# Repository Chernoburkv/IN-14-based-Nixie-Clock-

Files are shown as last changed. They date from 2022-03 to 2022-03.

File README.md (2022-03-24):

# IN-14-based-Nixie-Clock-
Nixie clock with date and calendar on 6 soviet nixie tubes with static indication and voltage doubler for nixies. 
Based on ds3231 and ATmega 8. Powers from 36-42VAC (for example a small transformer).
ECAD files for main & display board, Code::Blocks project, hex and fuse pic included.

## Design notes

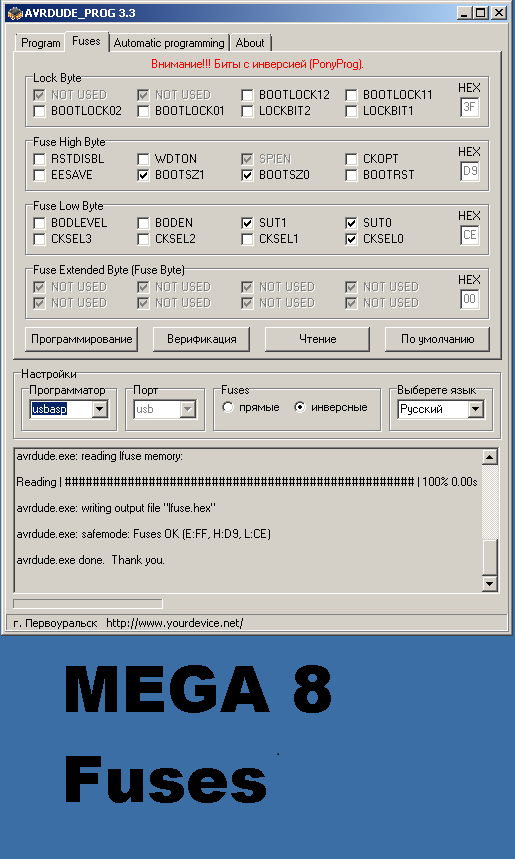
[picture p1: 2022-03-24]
mega8 fuses.png

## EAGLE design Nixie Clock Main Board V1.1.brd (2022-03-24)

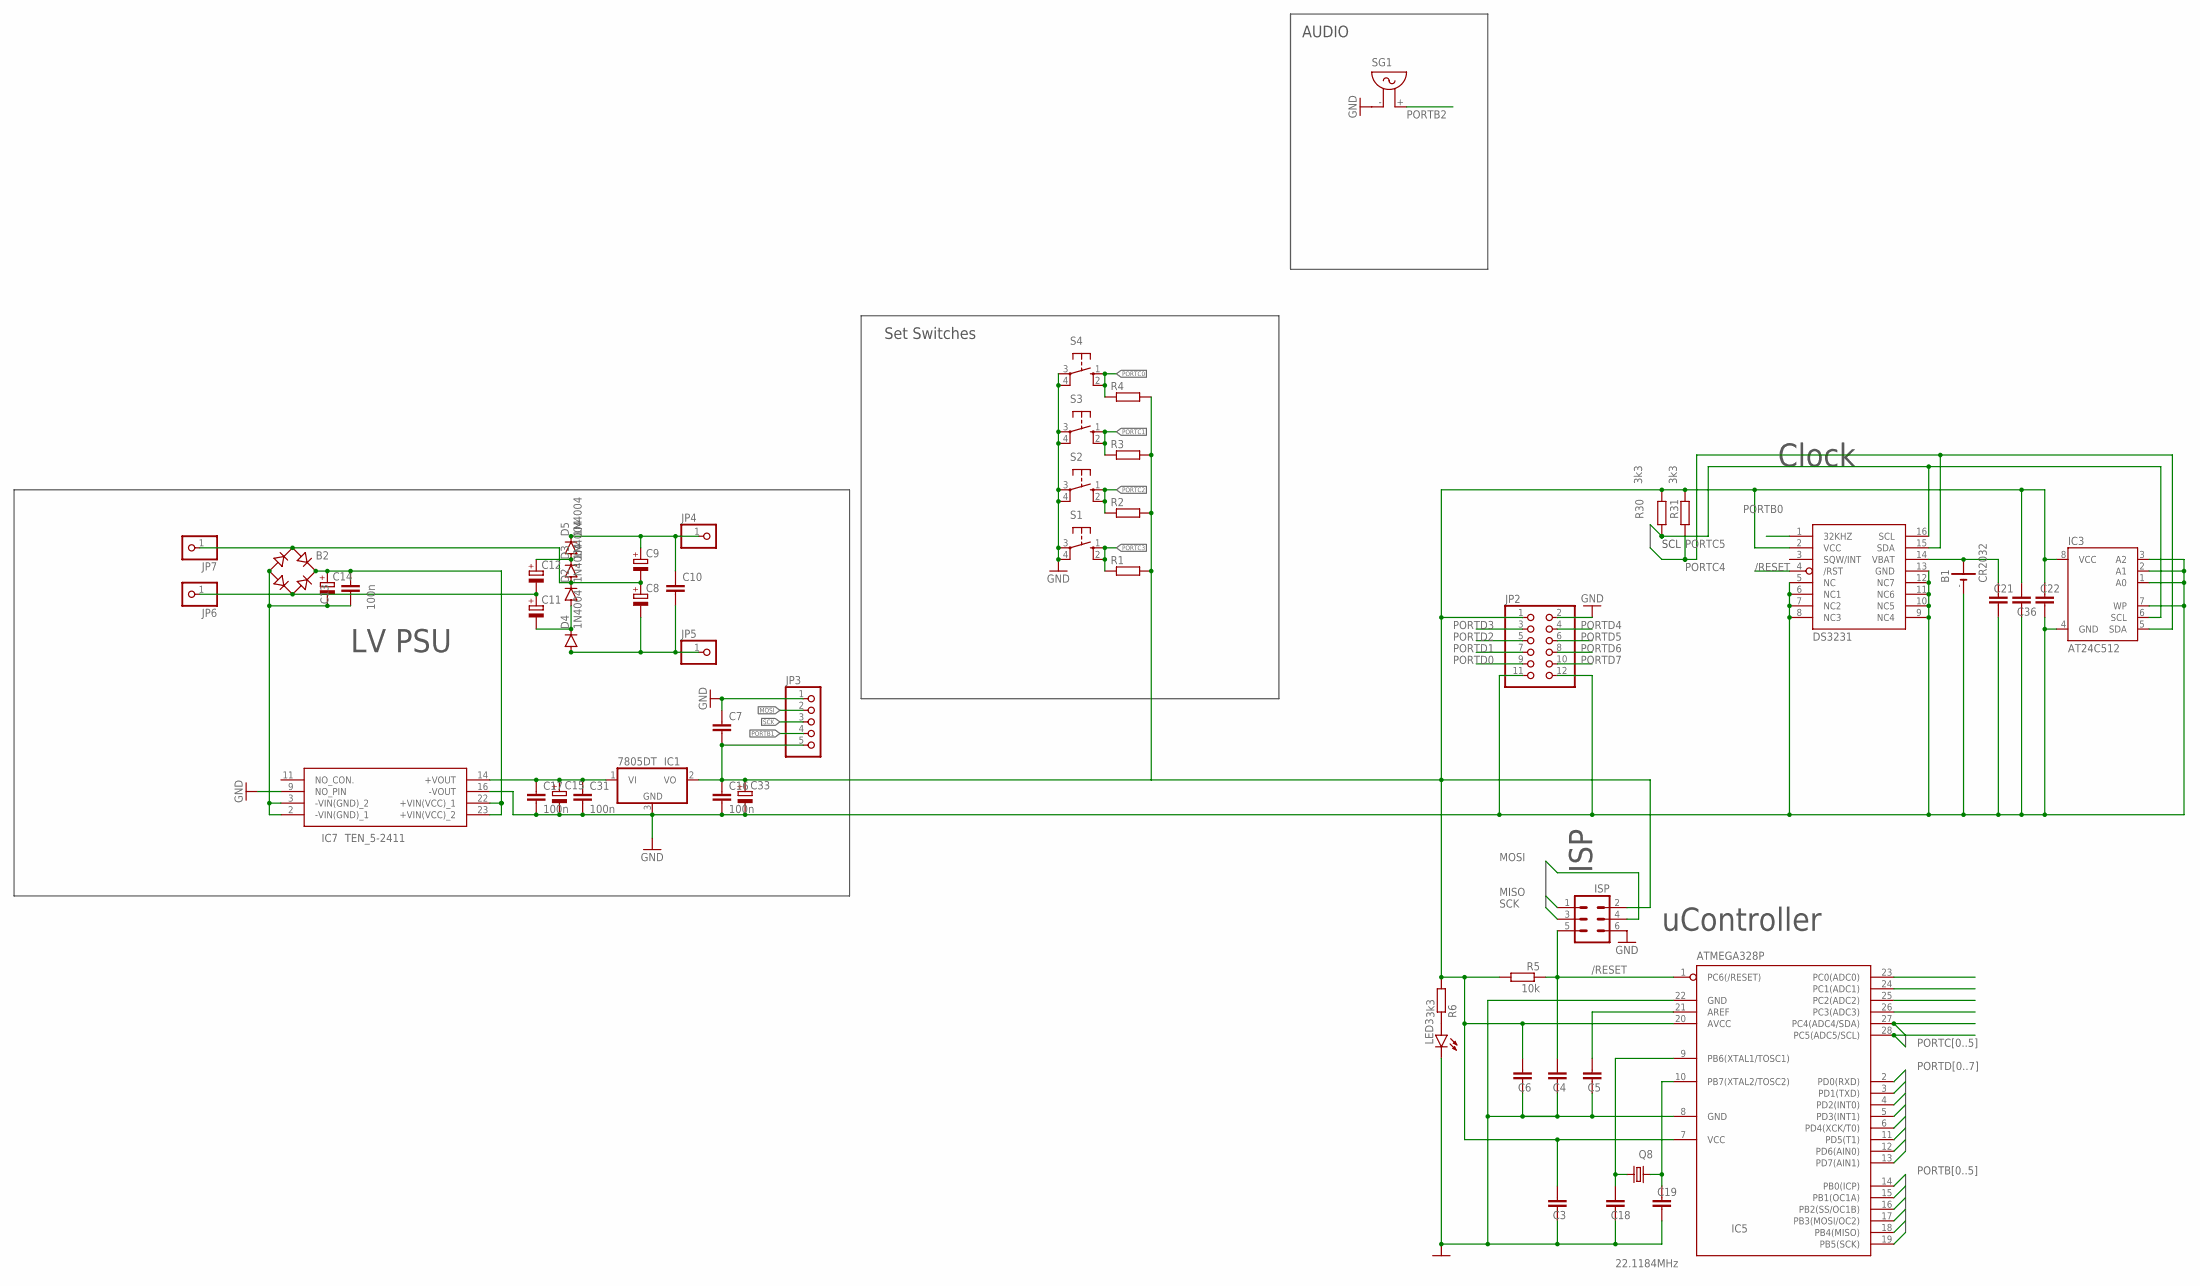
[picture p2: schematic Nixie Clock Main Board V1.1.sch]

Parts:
B1: CR2032
B2: B-DIL
C3, C5, C6, C21, C22, C36: C-EUC1206; C1206
C4, C7, C18, C19: C-EUC0805; C0805
C8, C9, C11, C12, C14: CPOL-EUTT5D11; TT5D11
C10: C-EU150-054X183; C150-054X183
C13: 100n; C050-025X075
C15, C33: CPOL-EUE3.5-8; E3,5-8
C16, C17, C31: 100n; C1206
D2, D3, D4, D5: 1N4004; DO41-10
IC1: 7805DT; TO252
IC3: AT24C512; DIL08
IC5: ATMEGA328P; DIL28-3
IC7: TEN_5-2411; TEN5SERIES
J: ISP; MA03-2
JP2: PINHD-2X6; 2X06
JP3: PINHD-1X5; 1X05
JP4, JP5, JP6, JP7: PINHD-1X1; 1X01
LED3: LED5MM
Q8: 22.1184MHz; HC49U-V
R1, R2, R3, R4: R-EU_R0805; R0805
R5: 10k; R0805
R6, R30, R31: 3k3; R0805
S1, S2, S3, S4: 10-XX; B3F-10XX
SG1: F/QMX
U2: DS3231; SO16W

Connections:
+5V: C3.1, C6.1, C7.2, C16.1, C22.1, C33.+, C36.1, IC1.2 (VO), IC3.8 (VCC), IC5.7 (VCC), IC5.20 (AVCC), J.2, JP2.1, JP3.5, R1.2, R2.2, R3.2, R4.2, R5.2, R6.2, R30.2, R31.2, U2.2 (VCC)
/RESET: C4.1, IC5.1 (PC6(/RESET)), J.5, R5.1, U2.4 (/RST)
GND: B1.-, C3.2, C4.2, C5.2, C6.2, C7.1, C15.-, C16.2, C17.2, C18.2, C19.2, C21.2, C22.2, C31.2, C33.-, C36.2, IC1.3 (GND), IC3.1 (A0), IC3.2 (A1), IC3.3 (A2), IC3.4 (GND), IC3.7 (WP), IC5.8 (GND), IC5.22 (GND), IC7.9 (NO_PIN), IC7.16 (-VOUT), J.6, JP2.2, JP2.11, JP2.12, JP3.1, LED3.K (C), S1.3, S1.4 (P1), S2.3, S2.4 (P1), S3.3, S3.4 (P1), S4.3, S4.4 (P1), SG1.- (1), U2.5 (NC), U2.6 (NC1), U2.7 (NC2), U2.8 (NC3), U2.9 (NC4), U2.10 (NC5), U2.11 (NC6), U2.12 (NC7), U2.13 (GND)
MISO: IC5.18 (PB4(MISO)), J.1
MOSI: IC5.17 (PB3(MOSI/OC2)), J.4, JP3.2
unnamed: C12.+, D3.C, D5.A
unnamed: B2.AC1, C8.+, C9.-, D2.C, D3.A, JP7.1
unnamed: C11.-, D2.A, D4.C
unnamed: B2.AC2, C11.+, C12.-, JP6.1
unnamed: B2.+, C13.2, C14.+, IC7.22 (+VIN(VCC)_1), IC7.23 (+VIN(VCC)_2)
unnamed: C8.-, C10.2, D4.A, JP5.1
unnamed: C9.+, C10.1, D5.C, JP4.1
unnamed: LED3.A, R6.1
unnamed: B2.-, C13.1, C14.-, IC7.2 (-VIN(GND)_1), IC7.3 (-VIN(GND)_2)
unnamed: C18.1, IC5.9 (PB6(XTAL1/TOSC1)), Q8.1
unnamed: C19.1, IC5.10 (PB7(XTAL2/TOSC2)), Q8.2
unnamed: B1.+, C21.1, U2.14 (VBAT)
unnamed: C5.1, IC5.21 (AREF)
unnamed: C15.+, C17.1, C31.1, IC1.1 (VI), IC7.14 (+VOUT)
PORTB0: IC5.14 (PB0(ICP)), U2.1 (32KHZ)
PORTB1: IC5.15 (PB1(OC1A)), JP3.4
PORTB2: IC5.16 (PB2(SS/OC1B)), SG1.+ (2)
PORTC0: IC5.23 (PC0(ADC0)), R4.1, S4.1 (S), S4.2 (S1)
PORTC1: IC5.24 (PC1(ADC1)), R3.1, S3.1 (S), S3.2 (S1)
PORTC2: IC5.25 (PC2(ADC2)), R2.1, S2.1 (S), S2.2 (S1)
PORTC3: IC5.26 (PC3(ADC3)), R1.1, S1.1 (S), S1.2 (S1)
PORTC4: IC3.5 (SDA), IC5.27 (PC4(ADC4/SDA)), R31.1, U2.15 (SDA)
PORTC5: IC3.6 (SCL), IC5.28 (PC5(ADC5/SCL)), R30.1, U2.16 (SCL)
PORTD0: IC5.2 (PD0(RXD)), JP2.9
PORTD1: IC5.3 (PD1(TXD)), JP2.7
PORTD2: IC5.4 (PD2(INT0)), JP2.5
PORTD3: IC5.5 (PD3(INT1)), JP2.3
PORTD4: IC5.6 (PD4(XCK/T0)), JP2.4
PORTD5: IC5.11 (PD5(T1)), JP2.6
PORTD6: IC5.12 (PD6(AIN0)), JP2.8
PORTD7: IC5.13 (PD7(AIN1)), JP2.10
SCK: IC5.19 (PB5(SCK)), J.3, JP3.3

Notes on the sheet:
Set Switches
AUDIO
LV PSU
Clock
uController
SCL
ISP

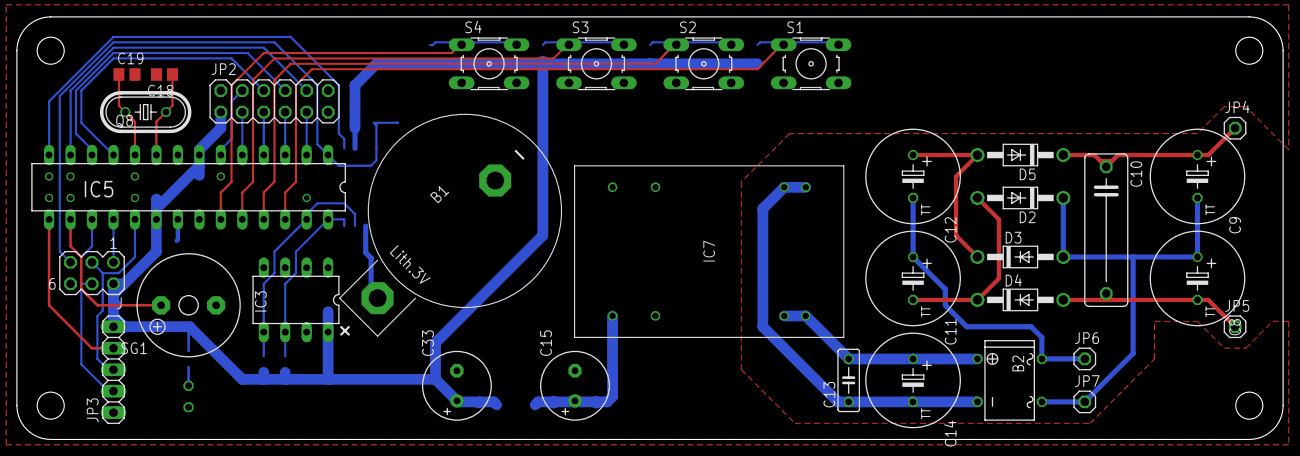
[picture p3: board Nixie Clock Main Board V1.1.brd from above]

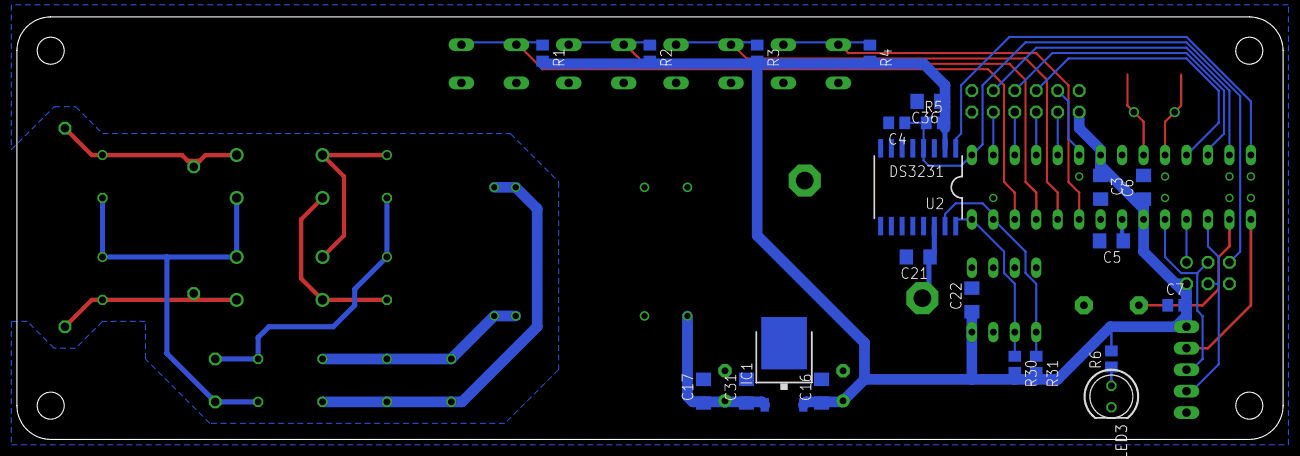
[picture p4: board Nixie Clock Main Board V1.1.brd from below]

Board: 2 copper layers, 149.8 x 50.0 mm, 56 parts (22 on the bottom side), 37 nets.

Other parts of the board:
U$3: 50X150

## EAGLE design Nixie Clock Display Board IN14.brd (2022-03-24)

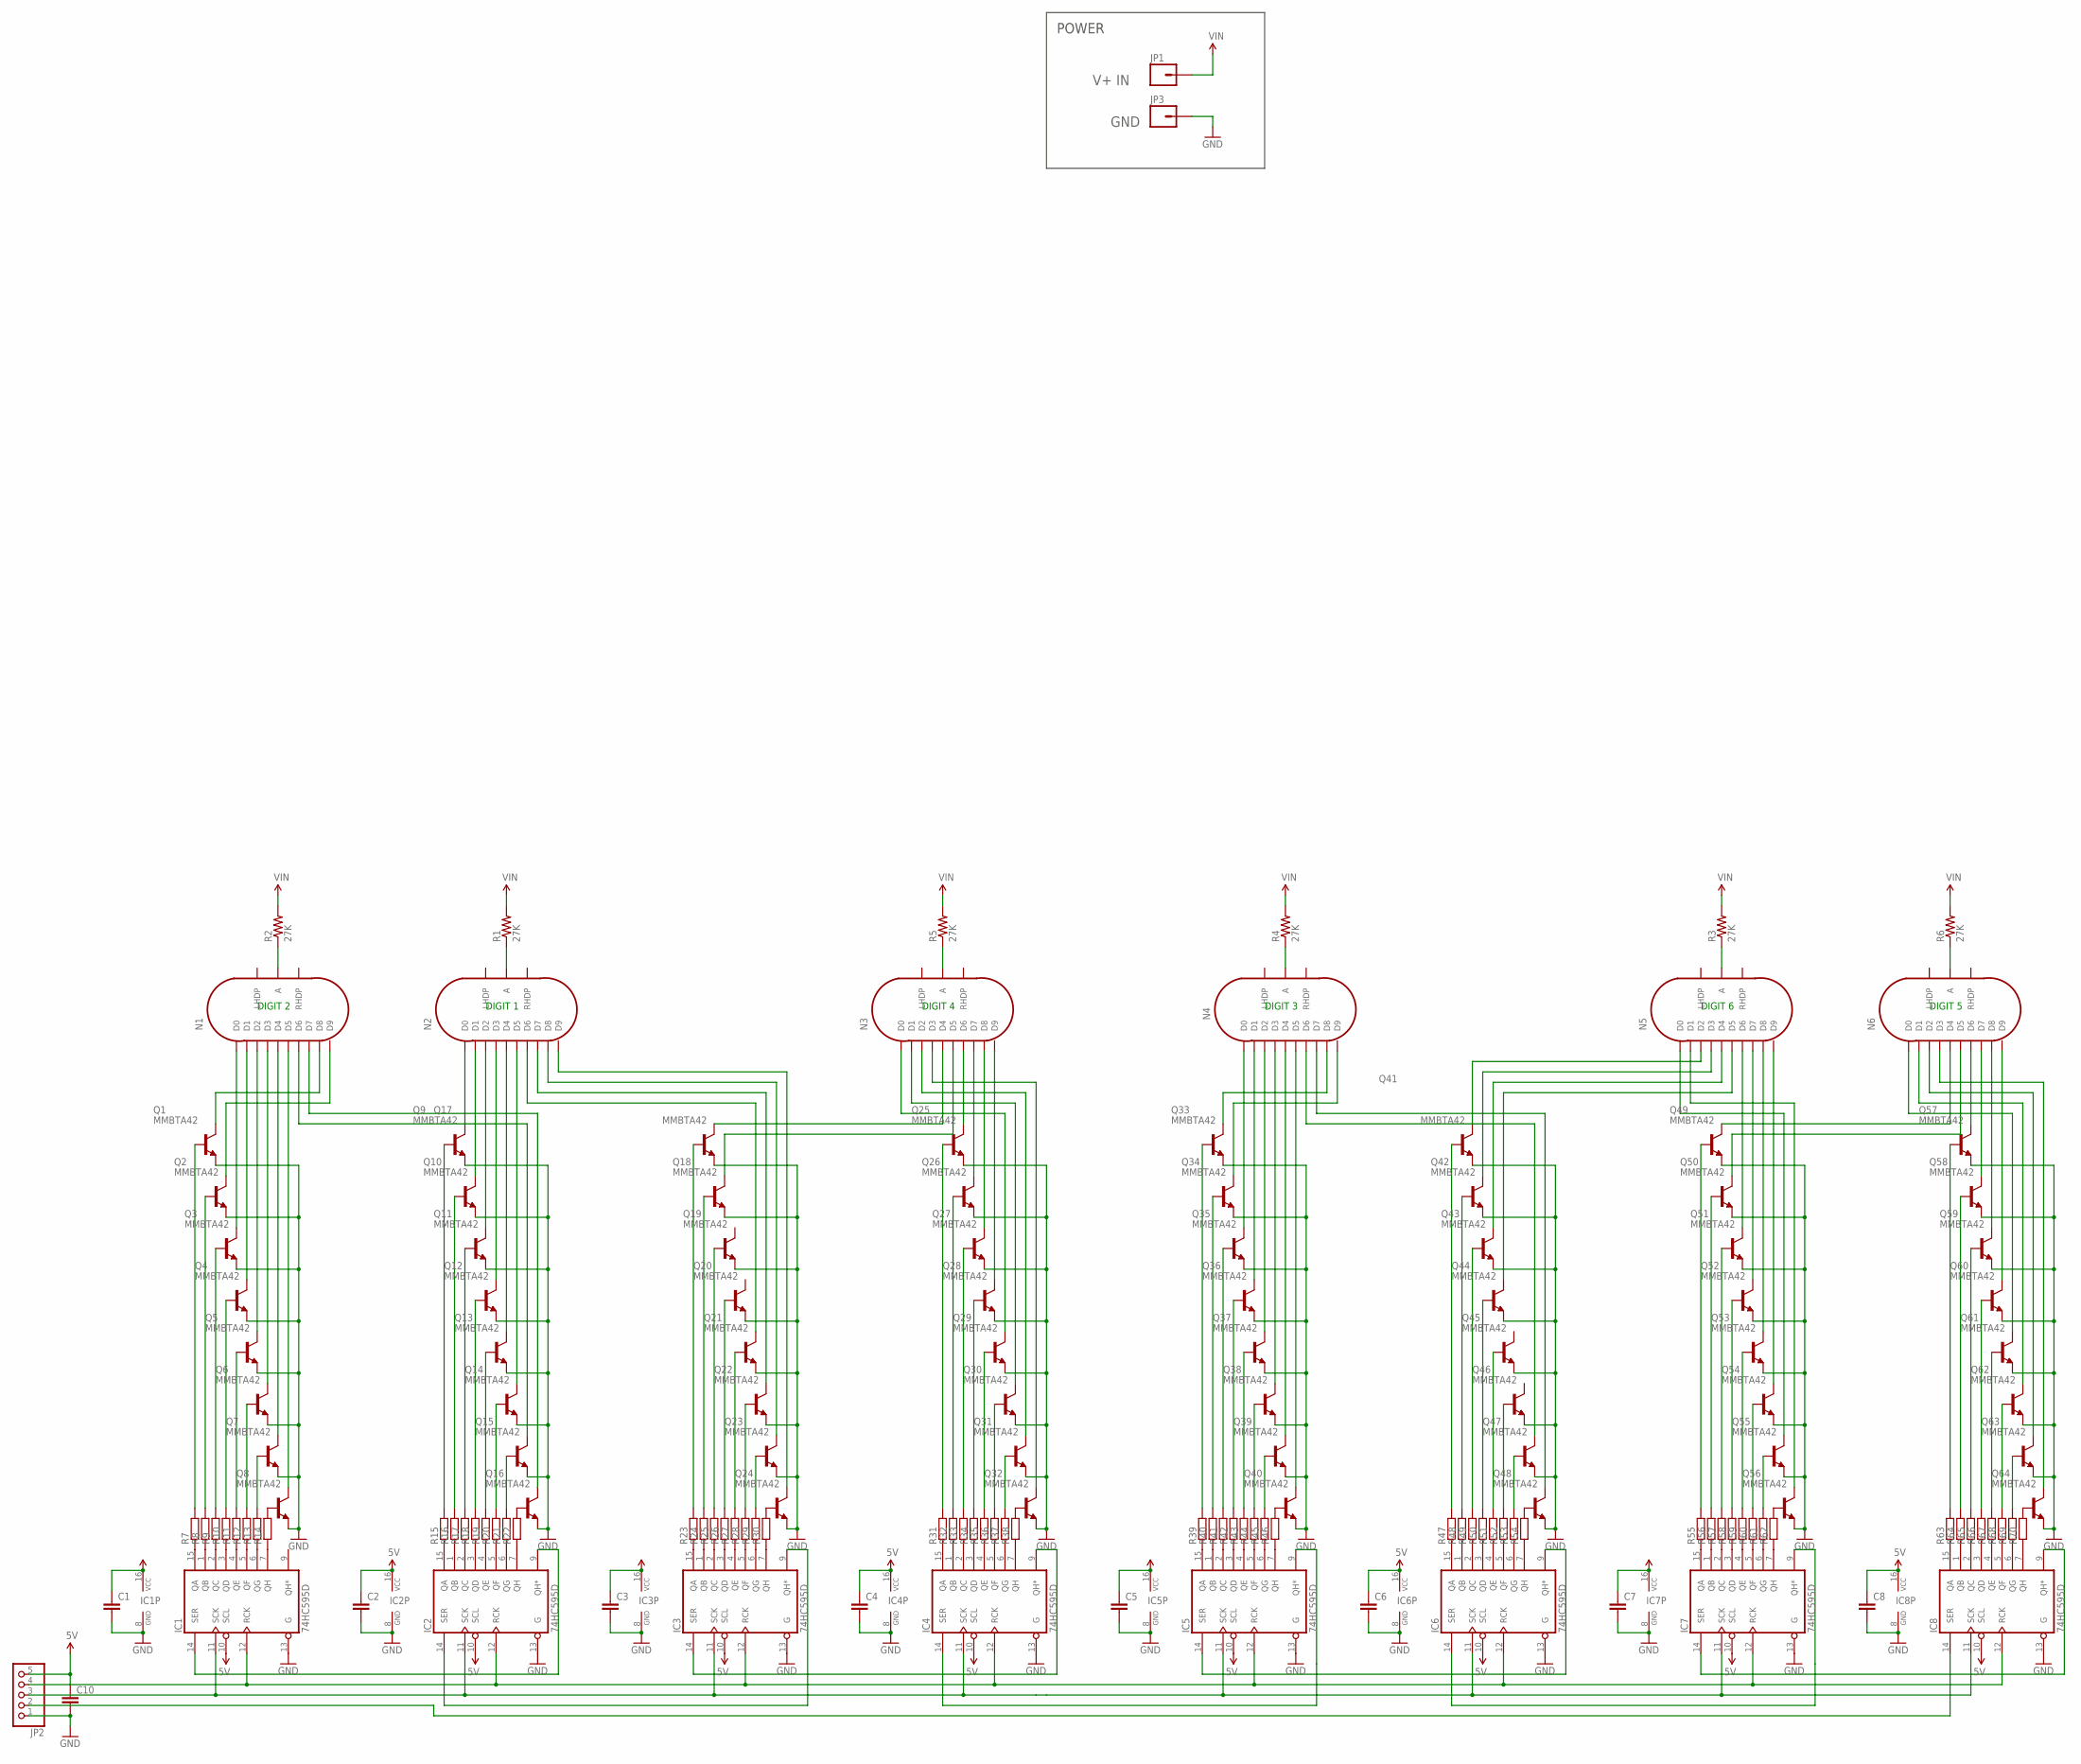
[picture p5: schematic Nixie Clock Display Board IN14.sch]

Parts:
C1, C2, C3, C4, C5, C6, C7, C8, C10: C-EUC0805; C0805
IC1, IC2, IC3, IC4, IC5, IC6, IC7, IC8: 74HC595D; SO16
JP1, JP3: M01PTH; 1X01
JP2: PINHD-1X5; 1X05
N1, N2, N3, N4, N5, N6: IN-14
Q1, Q2, Q3, Q4, Q5, Q6, Q7, Q8, Q9, Q10, Q11, Q12, Q13, Q14, Q15, Q16, Q17, Q18, Q19, Q20, Q21, Q22, Q23, Q24, Q25, Q26, Q27, Q28, Q29, Q30, Q31, Q32, Q33, Q34, Q35, Q36, Q37, Q38, Q39, Q40, Q41, Q42, Q43, Q44, Q45, Q46, Q47, Q48, Q49, Q50, Q51, Q52, Q53, Q54, Q55, Q56, Q57, Q58, Q59, Q60, Q61, Q62, Q63, Q64: MMBTA42; SOT23
R1, R2, R3, R4, R5, R6: 27K; AXIAL-0.5
R7, R8, R9, R10, R11, R12, R13, R14, R15, R16, R17, R18, R19, R20, R21, R22, R23, R24, R25, R26, R27, R28, R29, R30, R31, R32, R33, R34, R35, R36, R37, R38, R39, R40, R41, R42, R43, R44, R45, R46, R47, R48, R49, R50, R51, R52, R53, R54, R55, R56, R57, R58, R59, R60, R61, R62, R63, R64, R65, R66, R67, R68, R69, R70: R-EU_R0805; R0805

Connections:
5V: C1.1, C2.1, C3.1, C4.1, C5.1, C6.1, C7.1, C8.1, C10.1, IC1.10 (SCL), IC1.16 (VCC), IC2.10 (SCL), IC2.16 (VCC), IC3.10 (SCL), IC3.16 (VCC), IC4.10 (SCL), IC4.16 (VCC), IC5.10 (SCL), IC5.16 (VCC), IC6.10 (SCL), IC6.16 (VCC), IC7.10 (SCL), IC7.16 (VCC), IC8.10 (SCL), IC8.16 (VCC), JP2.5
GND: C1.2, C2.2, C3.2, C4.2, C5.2, C6.2, C7.2, C8.2, C10.2, IC1.8 (GND), IC1.13 (G), IC2.8 (GND), IC2.13 (G), IC3.8 (GND), IC3.13 (G), IC4.8 (GND), IC4.13 (G), IC5.8 (GND), IC5.13 (G), IC6.8 (GND), IC6.13 (G), IC7.8 (GND), IC7.13 (G), IC8.8 (GND), IC8.13 (G), JP2.1, JP3.1, Q1.2 (E), Q2.2 (E), Q3.2 (E), Q4.2 (E), Q5.2 (E), Q6.2 (E), Q7.2 (E), Q8.2 (E), Q9.2 (E), Q10.2 (E), Q11.2 (E), Q12.2 (E), Q13.2 (E), Q14.2 (E), Q15.2 (E), Q16.2 (E), Q17.2 (E), Q18.2 (E), Q19.2 (E), Q20.2 (E), Q21.2 (E), Q22.2 (E), Q23.2 (E), Q24.2 (E), Q25.2 (E), Q26.2 (E), Q27.2 (E), Q28.2 (E), Q29.2 (E), Q30.2 (E), Q31.2 (E), Q32.2 (E), Q33.2 (E), Q34.2 (E), Q35.2 (E), Q36.2 (E), Q37.2 (E), Q38.2 (E), Q39.2 (E), Q40.2 (E), Q41.2 (E), Q42.2 (E), Q43.2 (E), Q44.2 (E), Q45.2 (E), Q46.2 (E), Q47.2 (E), Q48.2 (E), Q49.2 (E), Q50.2 (E), Q51.2 (E), Q52.2 (E), Q53.2 (E), Q54.2 (E), Q55.2 (E), Q56.2 (E), Q57.2 (E), Q58.2 (E), Q59.2 (E), Q60.2 (E), Q61.2 (E), Q62.2 (E), Q63.2 (E), Q64.2 (E)
IN1: IC8.14 (SER), JP2.2
IN2: IC1.12 (RCK), IC2.12 (RCK), IC3.12 (RCK), IC4.12 (RCK), IC5.12 (RCK), IC6.12 (RCK), IC7.12 (RCK), IC8.12 (RCK), JP2.4
IN5: IC1.11 (SCK), IC2.11 (SCK), IC3.11 (SCK), IC4.11 (SCK), IC5.11 (SCK), IC6.11 (SCK), IC7.11 (SCK), IC8.11 (SCK), JP2.3
IN7: IC2.14 (SER), IC3.9 (QH*)
IN8: IC4.14 (SER), IC5.9 (QH*)
IN12: IC5.14 (SER), IC6.9 (QH*)
IN13: IC6.14 (SER), IC7.9 (QH*)
unnamed: Q1.1 (B), R7.2
unnamed: IC1.15 (QA), R7.1
unnamed: IC1.1 (QB), R8.1
unnamed: IC1.2 (QC), R9.1
unnamed: IC1.3 (QD), R10.1
unnamed: IC1.4 (QE), R11.1
unnamed: IC1.5 (QF), R12.1
unnamed: IC1.6 (QG), R13.1
unnamed: IC1.7 (QH), R14.1
unnamed: Q8.1 (B), R14.2
unnamed: Q7.1 (B), R13.2
unnamed: Q6.1 (B), R12.2
unnamed: Q5.1 (B), R11.2
unnamed: Q4.1 (B), R10.2
unnamed: Q3.1 (B), R9.2
unnamed: Q2.1 (B), R8.2
unnamed: Q9.1 (B), R15.2
unnamed: Q16.1 (B), R22.2
unnamed: Q15.1 (B), R21.2
unnamed: Q14.1 (B), R20.2
unnamed: Q13.1 (B), R19.2
unnamed: Q12.1 (B), R18.2
unnamed: Q11.1 (B), R17.2
unnamed: Q10.1 (B), R16.2
unnamed: N6.D0, Q61.3 (C)
unnamed: IC1.14 (SER), IC2.9 (QH*)
unnamed: N5.A, R3.P$1 (1)
unnamed: IC2.15 (QA), R15.1
unnamed: IC2.1 (QB), R16.1
unnamed: IC2.2 (QC), R17.1
unnamed: IC2.3 (QD), R18.1
unnamed: IC2.4 (QE), R19.1
unnamed: IC2.5 (QF), R20.1
unnamed: IC2.6 (QG), R21.1
unnamed: IC2.7 (QH), R22.1
unnamed: Q17.1 (B), R23.2
unnamed: Q24.1 (B), R30.2
unnamed: N6.A, R6.P$1 (1)
unnamed: Q23.1 (B), R29.2
unnamed: Q22.1 (B), R28.2
unnamed: Q21.1 (B), R27.2
unnamed: Q20.1 (B), R26.2
unnamed: Q19.1 (B), R25.2
unnamed: Q18.1 (B), R24.2
unnamed: IC3.15 (QA), R23.1
unnamed: IC3.1 (QB), R24.1
unnamed: IC3.2 (QC), R25.1
unnamed: IC3.3 (QD), R26.1
unnamed: IC3.4 (QE), R27.1
unnamed: IC3.5 (QF), R28.1
unnamed: IC3.6 (QG), R29.1
unnamed: IC3.7 (QH), R30.1
unnamed: N4.A, R4.P$1 (1)
unnamed: N3.A, R5.P$1 (1)
unnamed: IC3.14 (SER), IC4.9 (QH*)
unnamed: N6.D1, Q62.3 (C)
unnamed: IC7.14 (SER), IC8.9 (QH*)
unnamed: N6.D2, Q63.3 (C)
unnamed: N6.D3, Q64.3 (C)
unnamed: Q25.1 (B), R31.2
unnamed: Q32.1 (B), R38.2
unnamed: Q31.1 (B), R37.2
unnamed: Q30.1 (B), R36.2
unnamed: Q29.1 (B), R35.2
unnamed: Q28.1 (B), R34.2
unnamed: Q27.1 (B), R33.2
unnamed: Q26.1 (B), R32.2
unnamed: IC4.15 (QA), R31.1
unnamed: IC4.1 (QB), R32.1
unnamed: IC4.2 (QC), R33.1
unnamed: IC4.3 (QD), R34.1
unnamed: IC4.4 (QE), R35.1
unnamed: IC4.5 (QF), R36.1
unnamed: IC4.6 (QG), R37.1
unnamed: IC4.7 (QH), R38.1
unnamed: Q33.1 (B), R39.2
unnamed: Q40.1 (B), R46.2
unnamed: Q39.1 (B), R45.2
unnamed: Q38.1 (B), R44.2
unnamed: N2.A, R1.P$1 (1)
unnamed: N1.A, R2.P$1 (1)
unnamed: N6.D4, Q49.3 (C)
unnamed: N6.D5, Q50.3 (C)
unnamed: N6.D6, Q57.3 (C)
unnamed: N6.D7, Q58.3 (C)
unnamed: N6.D8, Q59.3 (C)
unnamed: N6.D9, Q60.3 (C)
unnamed: Q37.1 (B), R43.2
unnamed: Q36.1 (B), R42.2
unnamed: Q35.1 (B), R41.2
unnamed: Q34.1 (B), R40.2
unnamed: IC5.15 (QA), R39.1
unnamed: IC5.1 (QB), R40.1
unnamed: IC5.2 (QC), R41.1
unnamed: IC5.3 (QD), R42.1
unnamed: N3.D0, Q29.3 (C)
unnamed: N3.D1, Q30.3 (C)
unnamed: N3.D2, Q31.3 (C)
unnamed: N3.D3, Q32.3 (C)
unnamed: N3.D4, Q17.3 (C)
unnamed: N5.D0, Q55.3 (C)
unnamed: N3.D5, Q18.3 (C)
unnamed: N3.D6, Q25.3 (C)
unnamed: N3.D7, Q26.3 (C)
unnamed: N3.D8, Q27.3 (C)
unnamed: N3.D9, Q28.3 (C)
unnamed: IC5.4 (QE), R43.1
unnamed: IC5.5 (QF), R44.1
unnamed: IC5.6 (QG), R45.1
unnamed: IC5.7 (QH), R46.1
unnamed: Q41.1 (B), R47.2
unnamed: Q48.1 (B), R54.2
unnamed: Q47.1 (B), R53.2
unnamed: Q46.1 (B), R52.2
unnamed: N2.D0, Q9.3 (C)
unnamed: N2.D1, Q10.3 (C)
unnamed: N2.D2, Q11.3 (C)
unnamed: N2.D3, Q12.3 (C)
unnamed: N2.D4, Q13.3 (C)
unnamed: N2.D5, Q14.3 (C)
unnamed: N2.D6, Q21.3 (C)
unnamed: N2.D7, Q22.3 (C)
unnamed: N2.D8, Q23.3 (C)
unnamed: N2.D9, Q24.3 (C)
unnamed: N1.D0, Q3.3 (C)
unnamed: N1.D1, Q4.3 (C)
unnamed: N1.D2, Q5.3 (C)
unnamed: N1.D3, Q6.3 (C)
unnamed: N1.D4, Q7.3 (C)
unnamed: N1.D5, Q8.3 (C)
unnamed: N1.D6, Q15.3 (C)
unnamed: N1.D7, Q16.3 (C)
unnamed: N1.D8, Q1.3 (C)
unnamed: N1.D9, Q2.3 (C)
unnamed: Q45.1 (B), R51.2
unnamed: Q44.1 (B), R50.2
unnamed: Q43.1 (B), R49.2
unnamed: Q42.1 (B), R48.2
unnamed: IC6.15 (QA), R47.1
unnamed: IC6.1 (QB), R48.1
unnamed: IC6.2 (QC), R49.1
unnamed: IC6.3 (QD), R50.1
unnamed: IC6.4 (QE), R51.1
unnamed: IC6.5 (QF), R52.1
unnamed: IC6.6 (QG), R53.1
unnamed: IC6.7 (QH), R54.1
unnamed: Q49.1 (B), R55.2
unnamed: Q56.1 (B), R62.2
unnamed: Q55.1 (B), R61.2
unnamed: Q54.1 (B), R60.2
unnamed: Q53.1 (B), R59.2
unnamed: Q52.1 (B), R58.2
unnamed: Q51.1 (B), R57.2
unnamed: Q50.1 (B), R56.2
unnamed: IC7.15 (QA), R55.1
unnamed: IC7.1 (QB), R56.1
unnamed: IC7.2 (QC), R57.1
unnamed: IC7.3 (QD), R58.1
unnamed: IC7.4 (QE), R59.1
unnamed: IC7.5 (QF), R60.1
unnamed: IC7.6 (QG), R61.1
unnamed: IC7.7 (QH), R62.1
unnamed: Q57.1 (B), R63.2
unnamed: Q64.1 (B), R70.2
unnamed: Q63.1 (B), R69.2
unnamed: Q62.1 (B), R68.2
unnamed: Q61.1 (B), R67.2
unnamed: Q60.1 (B), R66.2
unnamed: Q59.1 (B), R65.2
unnamed: Q58.1 (B), R64.2
unnamed: IC8.15 (QA), R63.1
unnamed: IC8.1 (QB), R64.1
unnamed: IC8.2 (QC), R65.1
unnamed: IC8.3 (QD), R66.1
unnamed: IC8.4 (QE), R67.1
unnamed: IC8.5 (QF), R68.1
unnamed: IC8.6 (QG), R69.1
unnamed: IC8.7 (QH), R70.1
unnamed: N5.D1, Q56.3 (C)
unnamed: N5.D2, Q41.3 (C)
unnamed: N5.D3, Q42.3 (C)
unnamed: N5.D4, Q43.3 (C)
unnamed: N5.D5, Q44.3 (C)
unnamed: N5.D6, Q51.3 (C)
unnamed: N5.D7, Q52.3 (C)
unnamed: N5.D8, Q53.3 (C)
unnamed: N5.D9, Q54.3 (C)
unnamed: N4.D0, Q35.3 (C)
unnamed: N4.D1, Q36.3 (C)
unnamed: N4.D2, Q37.3 (C)
unnamed: N4.D3, Q38.3 (C)
unnamed: N4.D4, Q39.3 (C)
unnamed: N4.D5, Q40.3 (C)
unnamed: N4.D6, Q47.3 (C)
unnamed: N4.D7, Q48.3 (C)
unnamed: N4.D8, Q33.3 (C)
unnamed: N4.D9, Q34.3 (C)
VIN: JP1.1, R1.P$2 (2), R2.P$2 (2), R3.P$2 (2), R4.P$2 (2), R5.P$2 (2), R6.P$2 (2)

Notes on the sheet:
V+ IN
DIGIT 6
DIGIT 5
POWER
GND
DIGIT 4
DIGIT 3
DIGIT 2
DIGIT 1

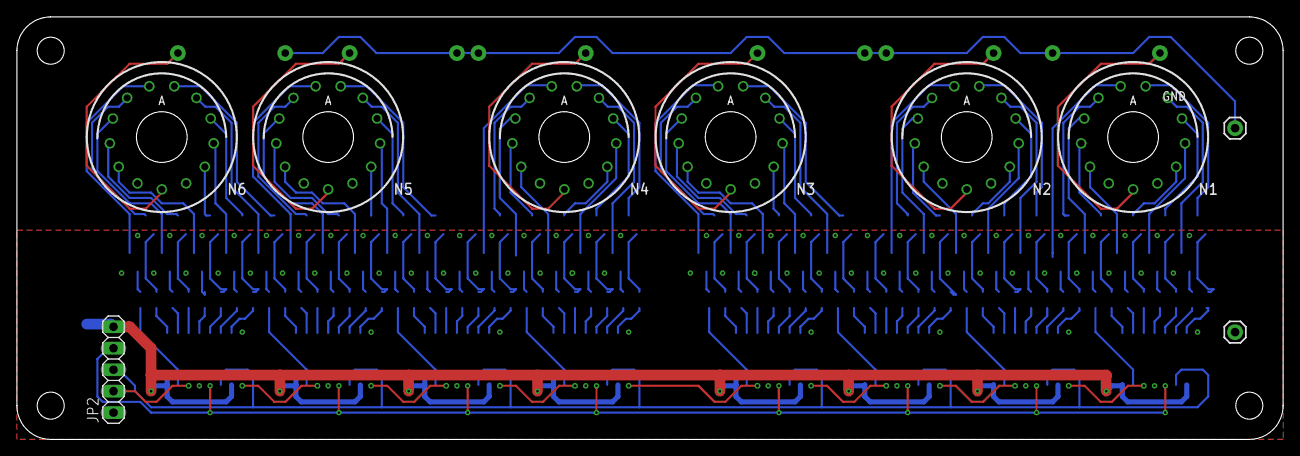
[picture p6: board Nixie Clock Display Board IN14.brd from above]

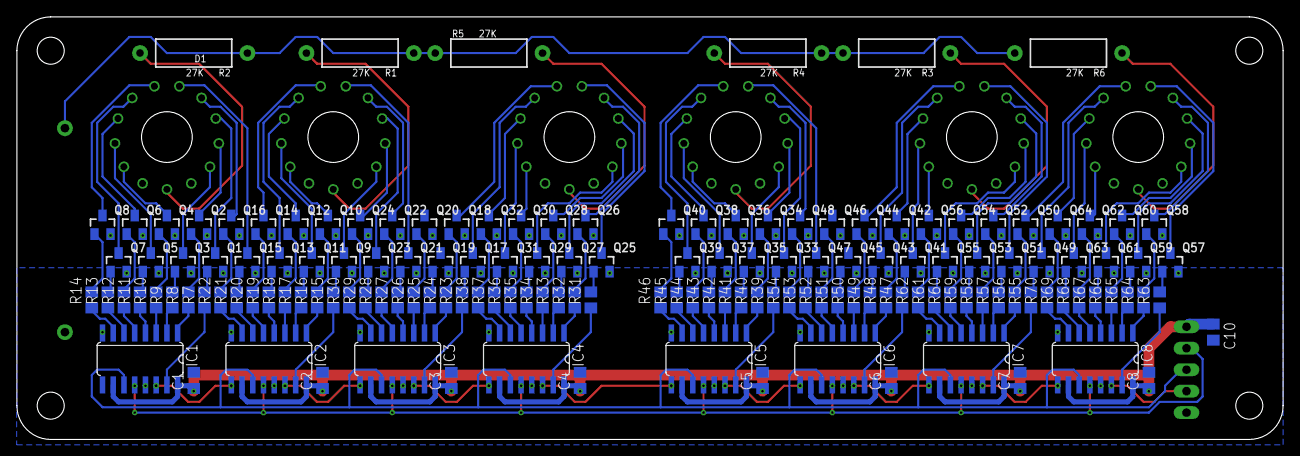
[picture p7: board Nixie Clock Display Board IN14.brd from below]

Board: 2 copper layers, 149.8 x 50.0 mm, 161 parts (151 on the bottom side), 207 nets.

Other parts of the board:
U$1: 50X150

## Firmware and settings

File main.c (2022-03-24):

#include <avr/io.h>
#include <avr/interrupt.h>
#include <util/delay.h>
#include <stdio.h>
#include <stdlib.h>
#include "DS3231.h"

#define SHIFT_REGISTER DDRB
#define SHIFT_PORT PORTB
#define LATCH (1<< PORTB1)     // LATCH
#define SS (1<< PORTB2)       // SS (NC)
#define DATA (1<< PORTB3)    //MOSI (SI)
#define CLOCK (1<< PORTB5)  //SCK (SCK)

#define BUTTON_REGISTER DDRC
#define BUTTON_PIN PINC
#define B0 (1 << PC0)    //0
#define B1 (1 << PC1)    //1
#define B2 (1 << PC2)    //2
#define B3 (1 << PC3)    //3

uint8_t dispstat=0;
uint8_t dispon=0;
uint8_t setstat=0;
uint8_t screen=0;
uint8_t sec_set=0;
uint8_t min_set=0;
uint8_t hour_set=12;
uint8_t date_set=1;
uint8_t mon_set=1;
uint8_t year_set=20;
uint8_t secdigit=0;

struct DS3231 rtc;
struct Time t;


uint8_t s10[] =
{
    0b00000100, //0
    0b00001000, //1
    0b00010000, //2
    0b00100000, //3
    0b01000000, //4
    0b10000000, //5
    0b00000000, //6--
    0b00000000, //7--
    0b00000001, //8
    0b00000010, //9
    0b00000000
};

uint8_t s11[] =
{
    0b00000000, //0--
    0b00000000, //1--
    0b00000000, //2--
    0b00000000, //3--
    0b00000000, //4--
    0b00000000, //5--
    0b01000000, //6
    0b10000000, //7
    0b00000000, //8--
    0b00000000, //9--
    0b00000000
};

uint8_t s20[] =
{
    0b00000001, //0
    0b00000010, //1
    0b00000100, //2
    0b00001000, //3
    0b00010000, //4
    0b00100000, //5
    0b00000000, //6--
    0b00000000, //7--
    0b00000000, //8--
    0b00000000, //9--
    0b00000000
};

uint8_t s21[] =
{
    0b00000000, //0--
    0b00000000, //1--
    0b00000000, //2--
    0b00000000, //3--
    0b00000000, //4--
    0b00000000, //5--
    0b00010000, //6
    0b00100000, //7
    0b01000000, //8
    0b10000000, //9
    0b00000000
};

uint8_t s30[] =
{
    0b00000000, //0--
    0b00000000, //1--
    0b00000000, //2--
    0b00000000, //3--
    0b00000001, //4
    0b00000010, //5
    0b00000000, //6--
    0b00000000, //7--
    0b00000000, //8--
    0b00000000, //9--
    0b00000000
};

uint8_t s31[] =
{
    0b00010000, //0
    0b00100000, //1
    0b01000000, //2
    0b10000000, //3
    0b00000000, //4--
    0b00000000, //5--
    0b00000001, //6
    0b00000010, //7
    0b00000100, //8
    0b00001000, //9
    0b00000000
};

uint8_t s50[] =
{
    0b00000000, //0--
    0b00000000, //1--
    0b00000001, //2
    0b00000010, //3
    0b00000100, //4
    0b00001000, //5
    0b00000000, //6--
    0b00000000, //7--
    0b00000000, //8--
    0b00000000, //9--
    0b00000000
};

uint8_t s51[] =
{
    0b01000000, //0
    0b10000000, //1
    0b00000000, //2--
    0b00000000, //3--
    0b00000000, //4--
    0b00000000, //5--
    0b00000100, //6
    0b00001000, //7
    0b00010000, //8
    0b00100000, //9
    0b00000000
};

int main(void)
{
  SHIFT_REGISTER|=(DATA | LATCH | CLOCK | SS); //Set control pins as outputs
  SHIFT_PORT &= ~(DATA | LATCH | CLOCK | SS); //Set control pins low
  SPCR=(1<< SPE) | (1<< MSTR) | (1<< SPR0) | (1<< SPR1);
  _delay_us(500);
  SPDR = 0b00000000;
  while(!(SPSR & (1<<SPIF)));//1
  SPDR = 0b00000000;
  while(!(SPSR & (1<<SPIF)));//2
  SPDR = 0b00000000;
  while(!(SPSR & (1<<SPIF)));//3
  SPDR = 0b00000000;
  while(!(SPSR & (1<<SPIF)));//4
  SPDR = 0b00000000;
  while(!(SPSR & (1<<SPIF)));//5
  SPDR = 0b00000000;
  while(!(SPSR & (1<<SPIF)));//6
  SPDR = 0b00000000;
  while(!(SPSR & (1<<SPIF)));//7
  SPDR = 0b00000000;
  while(!(SPSR & (1<<SPIF)));//8
  SHIFT_PORT |= (LATCH); //высокий уровень
  _delay_us(50);
  SHIFT_PORT &= ~(LATCH); //низкий уровень

  DS3231_begin();

  BUTTON_REGISTER &= ~(B0 | B1 | B2 | B3);

  cli();
   TCNT1  = 0;
   TCCR1A = 0;
   TCCR1B = 0;
   OCR1A = 62499;            // compare match register 16MHz/256/4Hz
   TCCR1B = ((1 << WGM12) | (1 << CS12) | (0 << CS11) | (0 << CS10));    // 256
   TIMSK = (1 << OCIE1A);
  sei();

    while(1)
    {

    }
}

void nix3x2numTo8x8Bits(uint8_t n1, uint8_t n2, uint8_t n3, uint8_t n4, uint8_t n5, uint8_t n6)
{
  SPDR =(s10[n1]); //1
  while(!(SPSR & (1<< SPIF))); //Wait for SPI process to finish

  SPDR = (s11[n1])|(s20[n2]); //2
  while(!(SPSR & (1<< SPIF))); //Wait for SPI process to finish

  SPDR = (s21[n2])|(s30[n3]); //3
  while(!(SPSR & (1<< SPIF))); //Wait for SPI process to finish

  SPDR = (s31[n3]); //4
  while(!(SPSR & (1<< SPIF))); //Wait for SPI process to finish


  SPDR = (s10[n4]); //5
  while(!(SPSR & (1<< SPIF))); //Wait for SPI process to finish

  SPDR = (s11[n4])|(s50[n5]); //6
  while(!(SPSR & (1<< SPIF))); //Wait for SPI process to finish

  SPDR = (s51[n5])|(s30[n6]); //7
  while(!(SPSR & (1<< SPIF))); //Wait for SPI process to finish

  SPDR = (s31[n6]); //8
  while(!(SPSR & (1<< SPIF))); //Wait for SPI process to finish
}

uint8_t number_days(uint8_t m, uint16_t y)
	{
		y=y+2000;
		uint16_t leap = (1 - (y % 4 + 2) % (y % 4 + 1)) * ((y % 100 + 2) % (y % 100 + 1)) + (1 - (y % 400 + 2) % (y % 400 + 1));
		return 28 + ((m + (m / 8)) % 2) + 2 % m + ((1 + leap) / m) + (1/m) - (leap/m);
	}

ISR(TIMER1_COMPA_vect) //This is the interrupt request, and the link is a good help about it --- https://sites.google.com/site/qeewiki/books/avr-guide/timers-on-the-atmega328
{
      if (!(PINC&B3))
             {
              if (dispstat<1){dispstat++;}
              else {
                     if (setstat==6)
                        {
                         DS3231_setTime(&rtc, hour_set, min_set, sec_set);
                         DS3231_setDate(&rtc, date_set, mon_set, 2000+year_set);
                         DS3231_setDOW(&rtc);
                        }
                        dispstat=0;
                        setstat=0;
                    }
              }

switch (dispstat)
{
     case 0 :
          if (!(PINC&B0))
             {
               if (screen<4){screen++;}
               else {screen=0;}
             }

          if (!(PINC&B1))
             {
               if (screen>0){screen--;}
               else {screen=3;}
             }


           t = DS3231_getTime(&rtc);
           secdigit = t.sec%10;
           //dispon=~((t.hour>=0)&&(t.hour<=4));
           switch (screen)
             {
               case 0:

                     if      ((t.sec<10)&&((t.min & 0b00000001)==1))
                             {
                              nix3x2numTo8x8Bits(secdigit, secdigit, secdigit, secdigit, secdigit, secdigit);
                             }
                     else if (((t.sec>=14)&&(t.sec<=15))||((t.sec>=44)&&(t.sec<=45)))
                             {
                              nix3x2numTo8x8Bits((t.year-2000)/10, (t.year-2000)%10, t.mon/10, t.mon%10, t.date/10, t.date%10);
                             }
                     else
                             {
                              nix3x2numTo8x8Bits(t.hour/10, t.hour%10, t.min/10, t.min%10, t.sec/10, secdigit);
                             }

               break;

               case 1:
                              nix3x2numTo8x8Bits(t.hour/10, t.hour%10, t.min/10, t.min%10, t.sec/10, secdigit);
               break;

               case 2:
                              nix3x2numTo8x8Bits((t.year-2000)/10, (t.year-2000)%10, t.mon/10, t.mon%10, t.date/10, t.date%10);
               break;

               case 3:
                              nix3x2numTo8x8Bits(((t.dow+5)%7)+1,10, 10, 10, 10, 10);
               break;

               case 4:
                              nix3x2numTo8x8Bits(secdigit, secdigit, secdigit, secdigit, secdigit, secdigit);
               break;


             }

     break;

     case 1 :
          if (!(PINC&B2))
             {
              if (setstat<6){setstat++;}
              else {setstat=0;}
             }

           switch (setstat)
           {
           case 0:

               if (!(PINC&B0))
                  {
                   if (hour_set<23){hour_set++;}
                   else {hour_set=0;}
                  }

               if (!(PINC&B1))
                  {
                   if (hour_set>0){hour_set--;}
                   else {hour_set=23;}
                  }
           nix3x2numTo8x8Bits(10, 10, 10, 10, hour_set/10, hour_set%10);
           break;
           case 1:
              if (!(PINC&B0))
                 {
                  if (min_set<59){min_set++;}
                  else {min_set=0;}
                 }

               if (!(PINC&B1))
                  {
                   if (min_set>0){min_set--;}
                   else {min_set=59;}
                  }
           nix3x2numTo8x8Bits(10, 10, hour_set/10, hour_set%10, min_set/10, min_set%10);
           break;
           case 2:
              if (!(PINC&B0))
                 {
                  if (sec_set<59){sec_set++;}
                  else {sec_set=0;}
                 }

               if (!(PINC&B1))
                  {
                   if (sec_set>0){sec_set--;}
                   else {sec_set=59;}
                  }
           nix3x2numTo8x8Bits(hour_set/10, hour_set%10, min_set/10, min_set%10, sec_set/10,sec_set%10);
           break;
           case 3:
              if  (!(PINC&B0))
                  {
                   if (year_set<99){year_set++;}
                   else {year_set=0;}
                   if (date_set>number_days(mon_set,year_set)) {date_set=number_days(mon_set,year_set);}
                  }

               if (!(PINC&B1))
                  {
                   if (year_set>0){year_set--;}
                   else {year_set=99;}
                   if (date_set>number_days(mon_set,year_set)) {date_set=number_days(mon_set,year_set);}
                  }
           nix3x2numTo8x8Bits(10, 10, 10, 10, year_set/10,year_set%10);
           break;
           case 4:
              if (!(PINC&B0))
                 {
                  if (mon_set<12){mon_set++;}
                  else {mon_set=1;}
                  if (date_set>number_days(mon_set,year_set)) {date_set=number_days(mon_set,year_set);}
                 }

              if (!(PINC&B1))
                 {
                  if (mon_set>1){mon_set--;}
                  else {mon_set=12;}
                  if (date_set>number_days(mon_set,year_set)) {date_set=number_days(mon_set,year_set);}
                 }
           nix3x2numTo8x8Bits(10, 10, year_set/10,year_set%10, mon_set/10,mon_set%10);
           break;
           case 5:
              if (!(PINC&B0))
                 {
                  if (date_set<number_days(mon_set,year_set)){date_set++;}
                  else {date_set=1;}
                 }

              if (!(PINC&B1))
                 {
                   if (date_set>1){date_set--;}
                   else {date_set=number_days(mon_set,year_set);}
                 }

            nix3x2numTo8x8Bits(year_set/10,year_set%10, mon_set/10,mon_set%10, date_set/10, date_set%10);
            break;
            case 6:
            nix3x2numTo8x8Bits(8,8,8,8,8,8);
            break;
            }
         break;
        }
      SHIFT_PORT |= LATCH; //Toggle latch to copy new data from the storage register to output register
      _delay_us(50);
      SHIFT_PORT &= ~LATCH;//data transmition from mc to the storage register

}

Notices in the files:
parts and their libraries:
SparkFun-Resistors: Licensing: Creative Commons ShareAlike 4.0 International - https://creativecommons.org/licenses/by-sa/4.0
